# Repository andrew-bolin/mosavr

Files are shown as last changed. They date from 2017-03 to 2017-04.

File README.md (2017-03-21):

# mosavr
Modular Open-Source Audio (Visual?) Receiver

I'm building a modular open-source AV receiver platform, with the following features
- Receive digital audio from TV via HDMI ARC
- Share control signals via HDMI CEC
- Multi-channel audio decoding and amplification
- Multiple outputs
- Apply DSP effects

Use-cases:
- Allow your TV remote to seamlessly control an existing analog amplifier/receiver
- Send a mono mixdown from your home cinema to the bathroom
- Room/speaker compensation
- Start with a 2.0 system, later upgrade to 5.1 

See https://hackaday.io/project/20469-modular-open-source-av-receiver for more detail on progress.

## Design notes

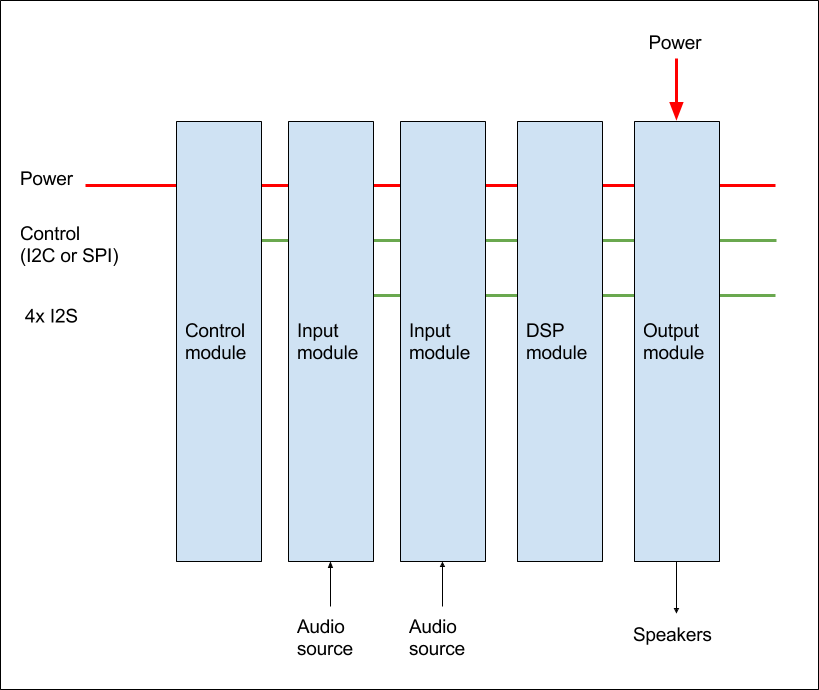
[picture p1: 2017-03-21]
docs/block dia.png

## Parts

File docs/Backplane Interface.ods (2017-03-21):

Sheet: Backplane Pinout
For counting purposes only... |  |  |  |  | Module dimensions (ideas)
A0 | 1 | 2 | A3? | Module (EEPROM) address | Low-profile PCI card: 64.41mm high, 119.91mm long, 15.24mm wide [between slots]
A1 | 3 | 4 | A4? |  | PCI-express x1 connectors have 18x2 pins, cost 50c ea
A2 | 5 | 6 | A5? |  | http://au.mouser.com/ProductDetail/Amphenol-FCI/10018784-10210TLF/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
Gnd | 7 | 8 |  |  | http://au.element14.com/amphenol-fci/10018783-10200tlf/card-edge-connector-receptacle/dp/1924223
3v3 | 9 | 10
 | 11 | 12
SCL | 13 | 14 | SDA
Gnd | 15 | 16 |  |  | 64-pin PCIe socket from 80c. I could kinda even use their pinout as inspiration...
MCLK | 17 | 18 |  | Depending on module’s capabilities and control instructions, these may be modified before being passed along | 98-pin ~$1.30
SCLK | 19 | 20 |  |  | 164-pin ~$1.05 (?!)
LRCLK | 21 | 22 |  |  | If I don't follow PCIe pinout, might make layout easier if Gnds on solder side and Vcc is on component side? [marginal]
I2S0 | 23 | 24 |  |  | (Probably want more grounds near the high-speed signals...)
I2S1 | 25 | 26
I2S2 | 27 | 28
I2S3 | 29 | 30 |  |  | TODO:
Gnd | 31 | 32 |  |  | Current rating per pin?
3v3 | 33 | 34 |  |  | Power budget for an average module
12v? | 35 | 36 |  | End of PCIe x1 | If I include a higher voltage, what is a sensible value? (Would +/- rails be of benefit, or just add rarely used complexity?)
 | 37 | 38
 | 39 | 40

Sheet: ID EEPROM
Chip | Memory | I/O | Addresses | Digikey Cost (AUD, qty 1) | Mouser (AUD) | element14 (AUD)
DS4250 | 64B | 9 | 8 | $4 | $4 | $6.75
PCA9500 | 256B | 8 | 8 | $2.50 | $2.60 | $2.60
PCA9501 | 256B | 8 | 64 | $2.70 | $2.70 | $2.70

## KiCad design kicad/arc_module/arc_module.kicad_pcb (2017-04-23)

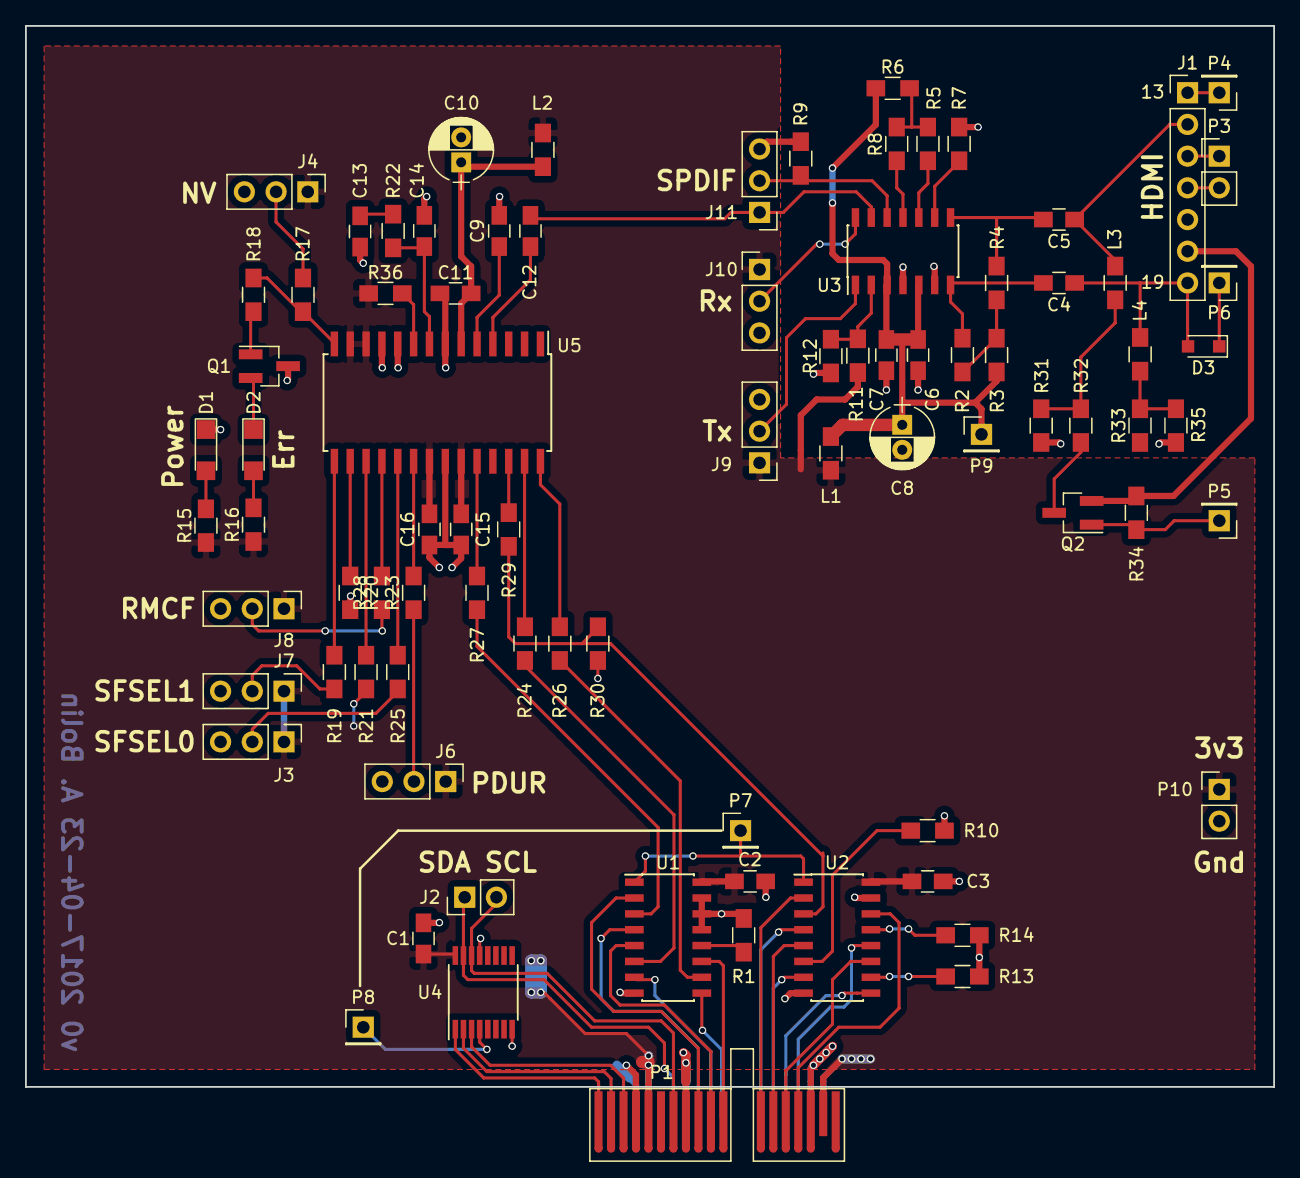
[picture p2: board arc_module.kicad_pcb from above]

Board: 2 copper layers, 100.0 x 85.0 mm, 85 parts (0 on the bottom side), 80 nets.

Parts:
C1, C2, C3: 0.1uF; C_0805_HandSoldering
C4, C5: 1u; C_0805_HandSoldering
C6, C7, C11, C15, C16: 0.1u; C_0805_HandSoldering
C8: 47u; CP_Radial_D5.0mm_P2.00mm
C9, C12: 0.01u; C_0805_HandSoldering
C10: 10u; CP_Radial_D5.0mm_P2.00mm
C13, C14: C_Small; C_0805_HandSoldering
D1, D2: LED_Small; LED_1206
D3: BAS16H; D_SOD-323_HandSoldering
J1: CONN_01X07; Pin_Header_Straight_1x07_Pitch2.54mm
J2: CONN_01X02; Pin_Header_Straight_1x02_Pitch2.54mm
J3, J4, J6, J7, J8, J9, J10, J11: CONN_01X03; Pin_Header_Straight_1x03_Pitch2.54mm
L1: 300ohm @ 100MHz; L_0805_HandSoldering
L2: Ferrite_Bead_Small; L_0805_HandSoldering
L3, L4: 300; L_0805_HandSoldering
P1: pcie_1x_edge; PCI-EXPRESS
P3, P10: CONN_01X02; Pin_Header_Straight_1x02_Pitch2.54mm
P4, P5, P6, P7, P8, P9: CONN_01X01; Pin_Header_Straight_1x01_Pitch2.54mm
Q1: BC847; SOT-23_Handsoldering
Q2: NTR4502; SOT-23_Handsoldering
R1, R9, R10, R13, R14, R34: 10k; R_0805_HandSoldering
R2, R4, R5, R8: 49.9; R_0805_HandSoldering
R3, R6: 5.1; R_0805_HandSoldering
R7: 39k; R_0805_HandSoldering
R11, R12: 1k; R_0805_HandSoldering
R15, R16, R22: R_Small; R_0805_HandSoldering
R17, R18, R19, R20, R21, R23, R25, R28, R30, R36: 47k; R_0805_HandSoldering
R24, R26, R27, R29: 33R; R_0805_HandSoldering
R31, R35: 5k1; R_0805_HandSoldering
R32, R33: 1k2; R_0805_HandSoldering
U1, U2: 74HCT157; SOIC-16_3.9x9.9mm_Pitch1.27mm
U3: EP91H0; SOIC-14_3.9x8.7mm_Pitch1.27mm
U4: PCA9500; TSSOP-16_4.4x5mm_Pitch0.65mm
U5: CS8416; SOIC-28W_7.5x17.9mm_Pitch1.27mm

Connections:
+3V3: C1.1, C2.1, C3.1, C15.1, C16.1, J3.1, J4.1, J6.1, J7.1, J8.1, J9.1, J10.1, L1.1, L2.2, P1.A5, P1.A17, P1.B5, P1.B17, P10.1, R11.1, R15.1, R16.1, R21.2, R36.2, U1.16, U2.16, U4.16, U5.12, U5.13, U5.21, U5.23
+5V: J1.6, Q2.2, R34.2
/CEC: J1.1, P4.1
/CS8416/LR_clk: R26.1, U1.10
/CS8416/M_clk: R27.1, U1.3
/CS8416/PDUR: J6.2, R23.1
/CS8416/RM/NV: J4.2, R17.2
/CS8416/RMCF: J8.2, R28.1
/CS8416/SFSEL0: J3.2, R25.1
/CS8416/SFSEL1: J7.2, R19.2
/CS8416/S_clk: R24.1, U1.6
/HDMI_HotPlug: D3.1, P6.1
/HDMI_SCL: J1.3, P3.1
/HDMI_SDA: J1.4, P3.2
/HEAC+: C5.1, J1.2, L3.2
/HEAC-: C4.1, D3.2, J1.7, L4.2
/Module Common/A0: P1.B1, U4.1
/Module Common/A1: P1.B2, U4.2
/Module Common/A2: P1.B3, U4.3
/Module Common/I2S0_in: P1.B12, U2.2
/Module Common/I2S0_mod: R29.1, R30.2, U2.3
/Module Common/I2S0_out: P1.A12, U2.4
/Module Common/I2S1_in: P1.B13, U2.5
/Module Common/I2S1_mod: R10.2, U2.6
/Module Common/I2S1_out: P1.A13, U2.7
/Module Common/I2S2_in: P1.B14, U2.11
/Module Common/I2S2_mod: R13.2, U2.10
/Module Common/I2S2_out: P1.A14, U2.9
/Module Common/I2S3_in: P1.B15, U2.14
/Module Common/I2S3_mod: R14.2, U2.13
/Module Common/I2S3_out: P1.A15, U2.12
/Module Common/IO0: P7.1, P8.1, U1.1, U2.1, U4.4
/Module Common/LRclk_in: P1.B11, U1.11
/Module Common/LRclk_out: P1.A11, U1.9
/Module Common/Mclk_in: P1.B9, U1.2
/Module Common/Mclk_out: P1.A9, U1.4
/Module Common/SCL: J2.2, P1.B7, U4.14
/Module Common/SDA: J2.1, P1.A7, U4.15
/Module Common/Sclk_in: P1.B10, U1.5
/Module Common/Sclk_out: P1.A10, U1.7
/Rx_En: J10.2, U3.14
/SPD_Rx: C12.2, J11.1, U3.13
/SPD_Tx: J11.2, R9.1, U3.12
/Tx_En: J9.2, U3.1
/arc tx/Ctrl_Tx: P5.1, Q2.1, R34.1
GND: C1.2, C2.2, C3.2, C6.2, C7.2, C8.2, C9.2, C10.2, C11.2, C13.2, C14.2, C15.2, C16.2, D1.1, J1.5, J3.3, J4.3, J6.3, J7.3, J8.3, J9.3, J10.3, J11.3, P1.A4, P1.A8, P1.A16, P1.B4, P1.B8, P1.B16, P10.2, Q1.3, R1.1, R7.2, R9.2, R10.1, R12.2, R13.1, R14.1, R20.2, R30.1, R31.2, R35.1, U1.8, U1.13, U1.14, U1.15, U2.8, U2.15, U3.4, U3.6, U4.8, U4.13, U5.7, U5.10, U5.11, U5.22, U5.25
unnamed: C4.2, R2.2, U3.7
unnamed: C5.2, R4.2, U3.8
unnamed: C9.1, U5.5
unnamed: C10.1, C11.1, L2.1, U5.6
unnamed: C12.1, U5.4
unnamed: C13.1, R22.2
unnamed: C14.1, R22.1, U5.8
unnamed: D1.2, R15.2
unnamed: D2.1, Q1.2
unnamed: D2.2, R16.2
unnamed: L3.1, R31.1, R32.2
unnamed: L4.1, R33.2, R35.2
unnamed: Q1.1, R18.2
unnamed: Q2.3, R32.1, R33.1
unnamed: R1.2, U1.12
unnamed: R2.1, R3.2, R4.1
unnamed: R5.1, R6.2, R8.1
unnamed: R5.2, U3.10
unnamed: R7.1, U3.9
unnamed: R8.2, U3.11
unnamed: R11.2, R12.1, U3.2
unnamed: R17.1, R18.1, U5.14
unnamed: R19.1, U5.15
unnamed: R20.1, U5.16
unnamed: R21.1, U5.17
unnamed: R23.2, U5.20
unnamed: R24.2, U5.27
unnamed: R25.2, U5.19
unnamed: R26.2, U5.28
unnamed: R27.2, U5.24
unnamed: R28.2, U5.18
unnamed: R29.2, U5.26
unnamed: R36.1, U5.9
VDDA: C6.1, C7.1, C8.1, L1.2, P9.1, R3.1, R6.1, U3.3, U3.5

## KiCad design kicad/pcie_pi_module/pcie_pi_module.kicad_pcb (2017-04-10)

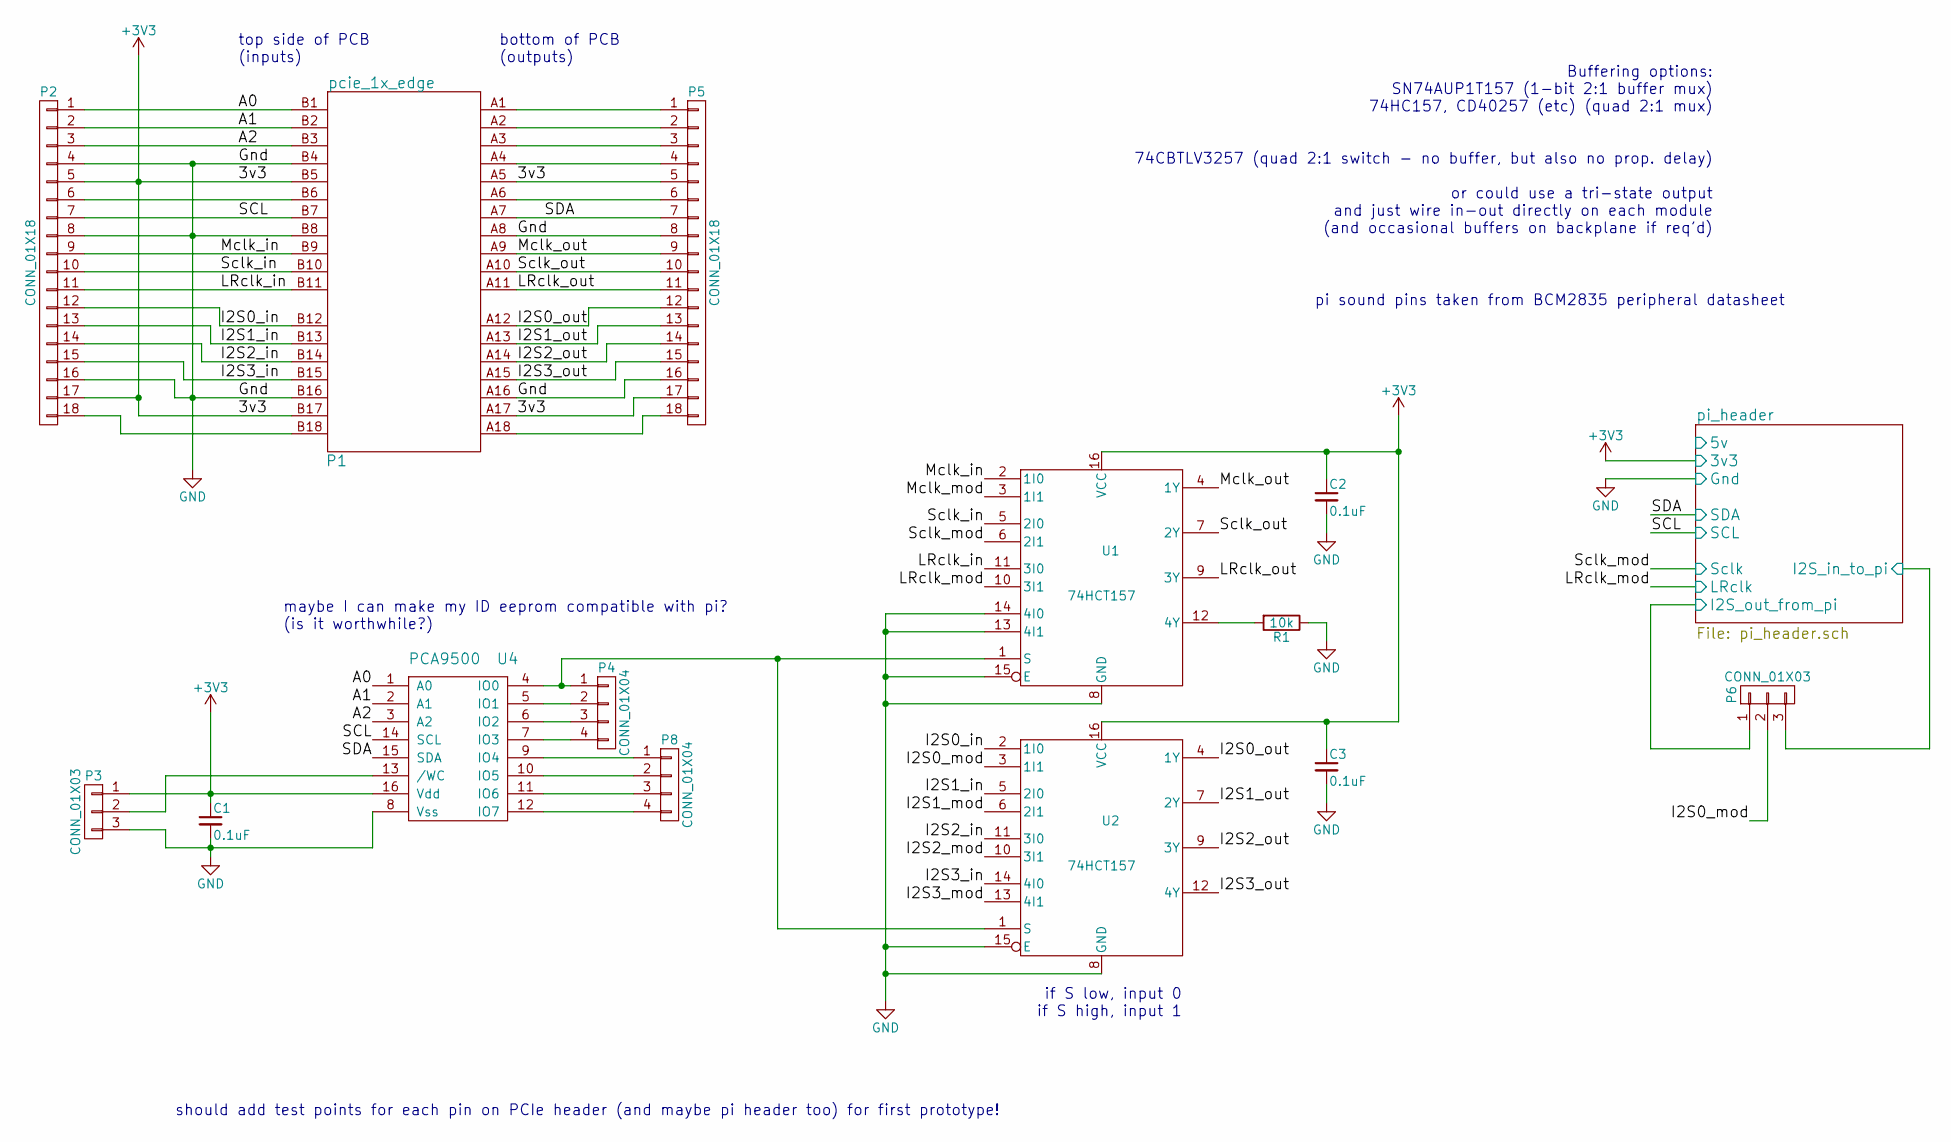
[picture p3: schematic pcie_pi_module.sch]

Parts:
C1, C2, C3: 0.1uF; C_0805_HandSoldering
P1: pcie_1x_edge; PCI-EXPRESS
P2, P5: CONN_01X18; smd_1x18_B
P3, P6: CONN_01X03; Pin_Header_Straight_1x03
P4, P8: CONN_01X04; Pin_Header_Straight_1x04
R1: 10k; R_0805_HandSoldering
U1, U2: 74HCT157; SOIC-16_3.9x9.9mm_Pitch1.27mm
U4: PCA9500; TSSOP-16_4.4x5mm_Pitch0.65mm

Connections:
+3V3: C1.1, C2.1, C3.1, P1.A5, P1.A17, P1.B5, P1.B17, P2.5, P2.17, P3.1, P5.5, P5.17, U1.16 (VCC), U2.16 (VCC), U4.16 (Vdd); also elsewhere on the board
/A0: P1.B1, P2.1, U4.1 (A0)
/A1: P1.B2, P2.2, U4.2 (A1)
/A2: P1.B3, P2.3, U4.3 (A2)
/I2S0_in: P1.B12, P2.12, U2.2 (1I0)
/I2S0_mod: P6.2, U2.3 (1I1)
/I2S0_out: P1.A12, P5.12, U2.4 (1Y)
/I2S1_in: P1.B13, P2.13, U2.5 (2I0)
/I2S1_mod: U2.6 (2I1)
/I2S1_out: P1.A13, P5.13, U2.7 (2Y)
/I2S2_in: P1.B14, P2.14, U2.11 (3I0)
/I2S2_mod: U2.10 (3I1)
/I2S2_out: P1.A14, P5.14, U2.9 (3Y)
/I2S3_in: P1.B15, P2.15, U2.14 (4I0)
/I2S3_mod: U2.13 (4I1)
/I2S3_out: P1.A15, P5.15, U2.12 (4Y)
/LRclk_in: P1.B11, P2.11, U1.11 (3I0)
/LRclk_mod: U1.10 (3I1); also elsewhere on the board
/LRclk_out: P1.A11, P5.11, U1.9 (3Y)
/Mclk_in: P1.B9, P2.9, U1.2 (1I0)
/Mclk_mod: U1.3 (1I1)
/Mclk_out: P1.A9, P5.9, U1.4 (1Y)
/SCL: P1.B7, P2.7, U4.14 (SCL); also elsewhere on the board
/SDA: P1.A7, P5.7, U4.15 (SDA); also elsewhere on the board
/Sclk_in: P1.B10, P2.10, U1.5 (2I0)
/Sclk_mod: U1.6 (2I1); also elsewhere on the board
/Sclk_out: P1.A10, P5.10, U1.7 (2Y)
/pi_header/I2S_in_to_pi: P6.3; also elsewhere on the board
/pi_header/I2S_out_from_pi: P6.1; also elsewhere on the board
GND: C1.2, C2.2, C3.2, P1.A8, P1.A16, P1.B4, P1.B8, P1.B16, P2.4, P2.8, P2.16, P3.3, P5.8, P5.16, R1.1, U1.8 (GND), U1.13 (4I1), U1.14 (4I0), U1.15 (E), U2.8 (GND), U2.15 (E), U4.8 (Vss); also elsewhere on the board
unnamed: P1.A1, P5.1
unnamed: P1.A2, P5.2
unnamed: P1.A3, P5.3
unnamed: P1.A4, P5.4
unnamed: P1.A6, P5.6
unnamed: P1.A18, P5.18
unnamed: P1.B6, P2.6
unnamed: P1.B18, P2.18
unnamed: P3.2, U4.13 (/WC)
unnamed: P4.1, U1.1 (S), U2.1 (S), U4.4 (IO0)
unnamed: P4.2, U4.5 (IO1)
unnamed: P4.3, U4.6 (IO2)
unnamed: P4.4, U4.7 (IO3)
unnamed: P8.1, U4.9 (IO4)
unnamed: P8.2, U4.10 (IO5)
unnamed: P8.3, U4.11 (IO6)
unnamed: P8.4, U4.12 (IO7)
unnamed: R1.2, U1.12 (4Y)

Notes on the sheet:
top side of PCB (inputs)
bottom of PCB (outputs)
if S low, input 0 if S high, input 1
Buffering options: SN74AUP1T157 (1-bit 2:1 buffer mux) 74HC157, CD40257 (etc) (quad 2:1 mux) 74CBTLV3257 (quad 2:1 switch - no buffer, but also no prop. delay) or could use a tri-state output and just wire in-out directly on each module (and occasional buffers on backplane if req'd)
maybe I can make my ID eeprom compatible with pi? (is it worthwhile?)
pi sound pins taken from BCM2835 peripheral datasheet
should add test points for each pin on PCIe header (and maybe pi header too) for first prototype!

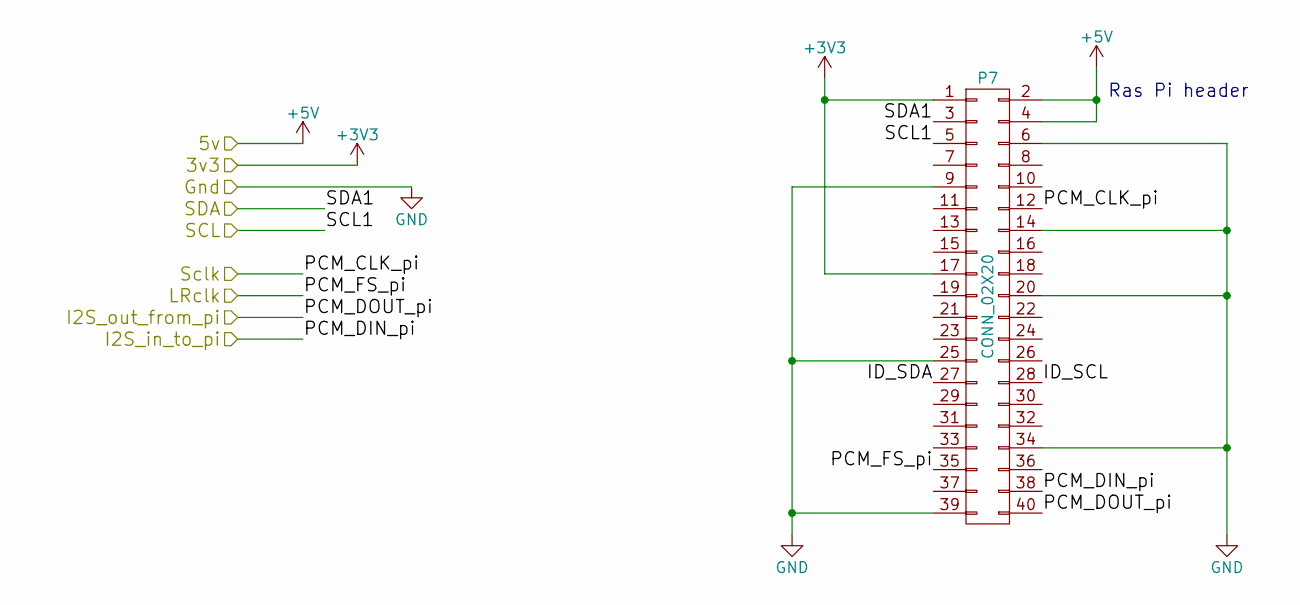
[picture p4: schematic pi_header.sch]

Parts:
P7: CONN_02X20; Pin_Header_Straight_2x20

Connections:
+3V3: P7.1, P7.17; also elsewhere on the board
+5V: P7.2, P7.4
/LRclk_mod: P7.35; also elsewhere on the board
/SCL: P7.5; also elsewhere on the board
/SDA: P7.3; also elsewhere on the board
/Sclk_mod: P7.12; also elsewhere on the board
/pi_header/I2S_in_to_pi: P7.38; also elsewhere on the board
/pi_header/I2S_out_from_pi: P7.40; also elsewhere on the board
/pi_header/ID_SCL: P7.28
/pi_header/ID_SDA: P7.27
GND: P7.6, P7.9, P7.14, P7.20, P7.25, P7.34, P7.39; also elsewhere on the board

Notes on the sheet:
Ras Pi header

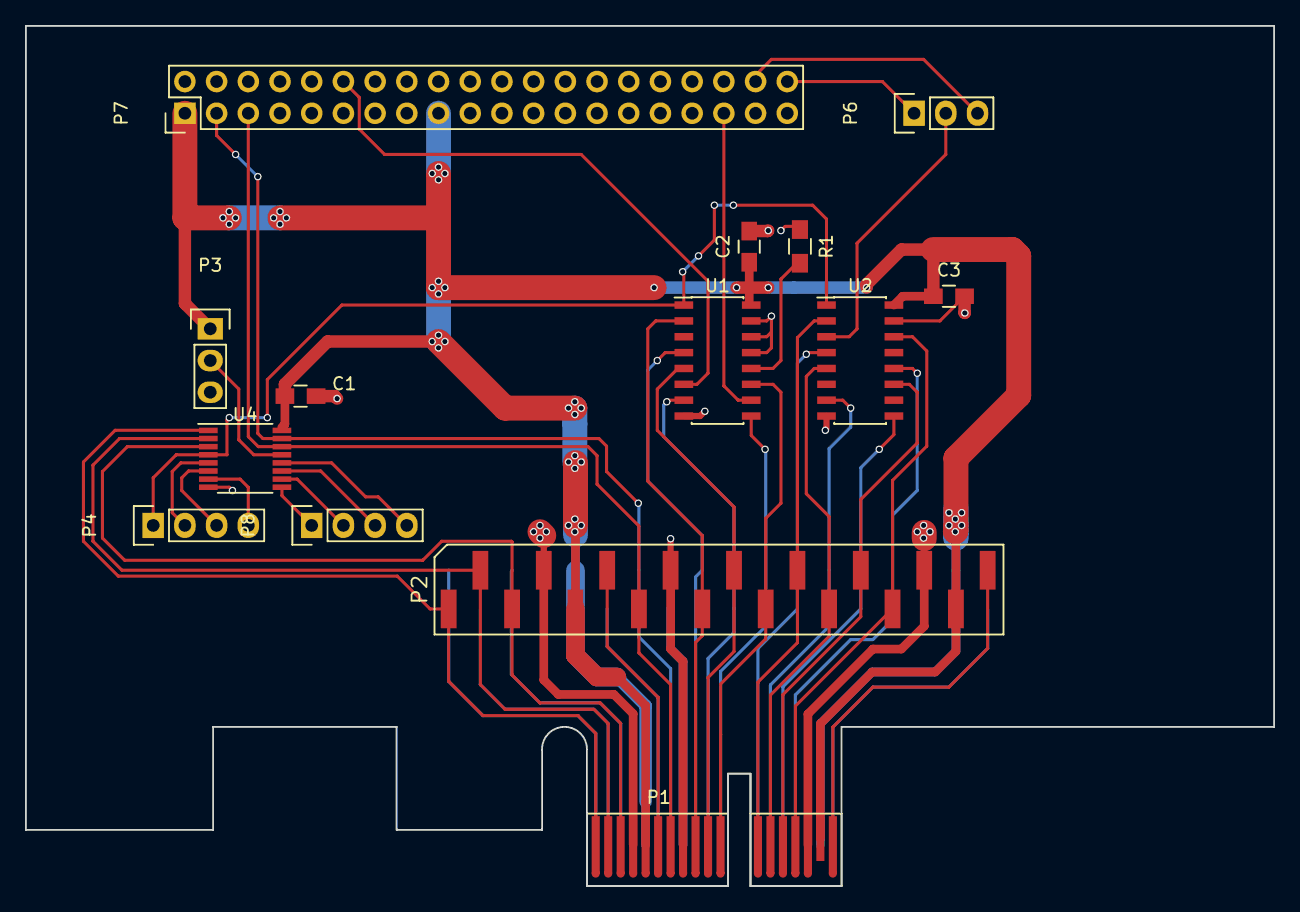
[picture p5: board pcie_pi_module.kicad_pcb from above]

Board: 2 copper layers, 100.0 x 68.9 mm, 15 parts (1 on the bottom side), 45 nets.

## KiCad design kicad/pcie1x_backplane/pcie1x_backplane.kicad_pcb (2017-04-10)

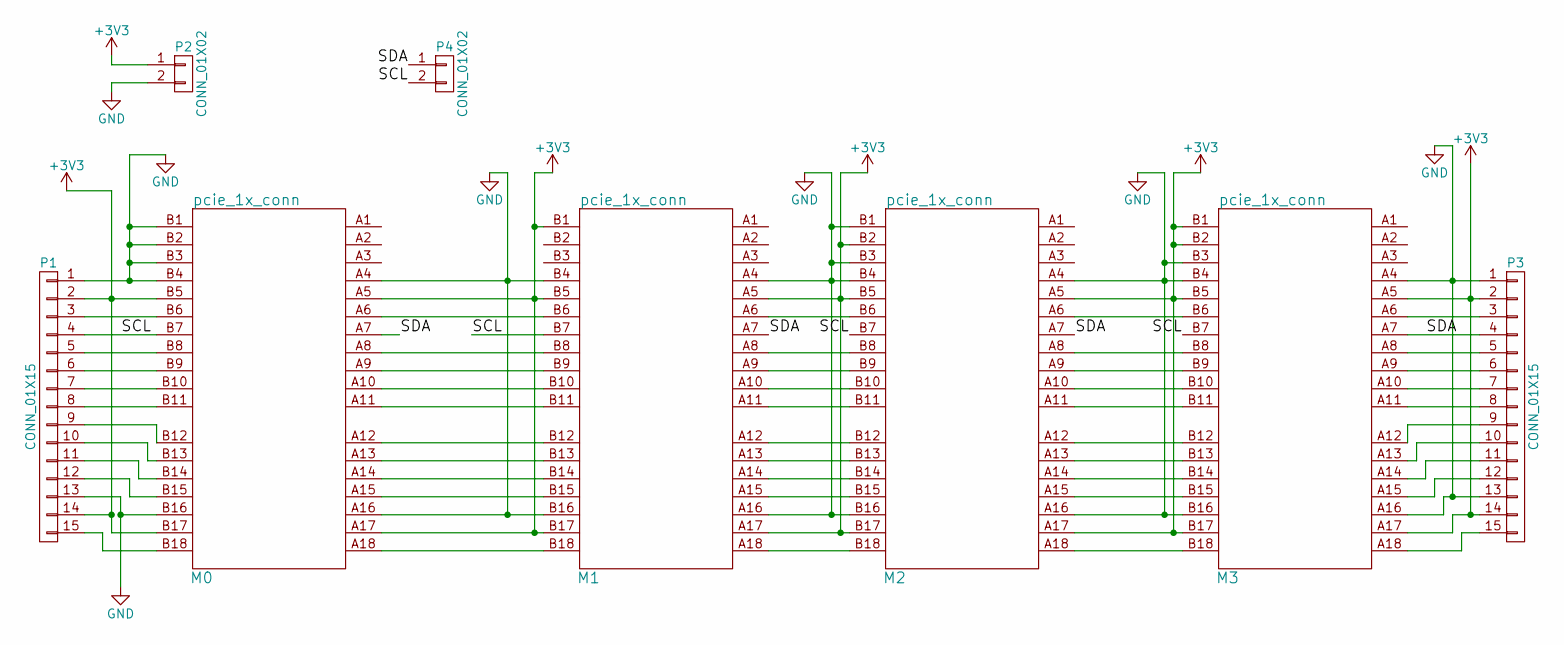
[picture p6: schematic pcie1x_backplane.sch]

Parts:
M0, M1, M2, M3: pcie_1x_conn; x1socket
P1, P3: CONN_01X15; Pin_Header_Straight_1x15
P2, P4: CONN_01X02; Pin_Header_Straight_1x02

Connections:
+3V3: M0.A5, M0.A17, M0.B5, M0.B17, M1.A5, M1.A17, M1.B1, M1.B5, M1.B17, M2.A5, M2.A17, M2.B2, M2.B5, M2.B17, M3.A5, M3.A17, M3.B1, M3.B2, M3.B5, M3.B17, P1.2, P1.14, P2.1, P3.2, P3.14
/SCL: M0.B7, M1.B7, M2.B7, M3.B7, P1.4, P4.2
/SDA: M0.A7, M1.A7, M2.A7, M3.A7, P3.4, P4.1
GND: M0.A4, M0.A16, M0.B1, M0.B2, M0.B3, M0.B4, M0.B16, M1.A4, M1.A16, M1.B4, M1.B16, M2.A4, M2.A16, M2.B1, M2.B3, M2.B4, M2.B16, M3.A4, M3.A16, M3.B3, M3.B4, M3.B16, P1.1, P1.13, P2.2, P3.1, P3.13
unnamed: M0.A6, M1.B6
unnamed: M0.A8, M1.B8
unnamed: M0.A9, M1.B9
unnamed: M0.A10, M1.B10
unnamed: M0.A11, M1.B11
unnamed: M0.A12, M1.B12
unnamed: M0.A13, M1.B13
unnamed: M0.A14, M1.B14
unnamed: M0.A15, M1.B15
unnamed: M0.A18, M1.B18
unnamed: M0.B6, P1.3
unnamed: M0.B8, P1.5
unnamed: M0.B9, P1.6
unnamed: M0.B10, P1.7
unnamed: M0.B11, P1.8
unnamed: M0.B12, P1.9
unnamed: M0.B13, P1.10
unnamed: M0.B14, P1.11
unnamed: M0.B15, P1.12
unnamed: M0.B18, P1.15
unnamed: M1.A6, M2.B6
unnamed: M1.A8, M2.B8
unnamed: M1.A9, M2.B9
unnamed: M1.A10, M2.B10
unnamed: M1.A11, M2.B11
unnamed: M1.A12, M2.B12
unnamed: M1.A13, M2.B13
unnamed: M1.A14, M2.B14
unnamed: M1.A15, M2.B15
unnamed: M1.A18, M2.B18
unnamed: M2.A6, M3.B6
unnamed: M2.A8, M3.B8
unnamed: M2.A9, M3.B9
unnamed: M2.A10, M3.B10
unnamed: M2.A11, M3.B11
unnamed: M2.A12, M3.B12
unnamed: M2.A13, M3.B13
unnamed: M2.A14, M3.B14
unnamed: M2.A15, M3.B15
unnamed: M2.A18, M3.B18
unnamed: M3.A6, P3.3
unnamed: M3.A8, P3.5
unnamed: M3.A9, P3.6
unnamed: M3.A10, P3.7
unnamed: M3.A11, P3.8
unnamed: M3.A12, P3.9
unnamed: M3.A13, P3.10
unnamed: M3.A14, P3.11
unnamed: M3.A15, P3.12
unnamed: M3.A18, P3.15

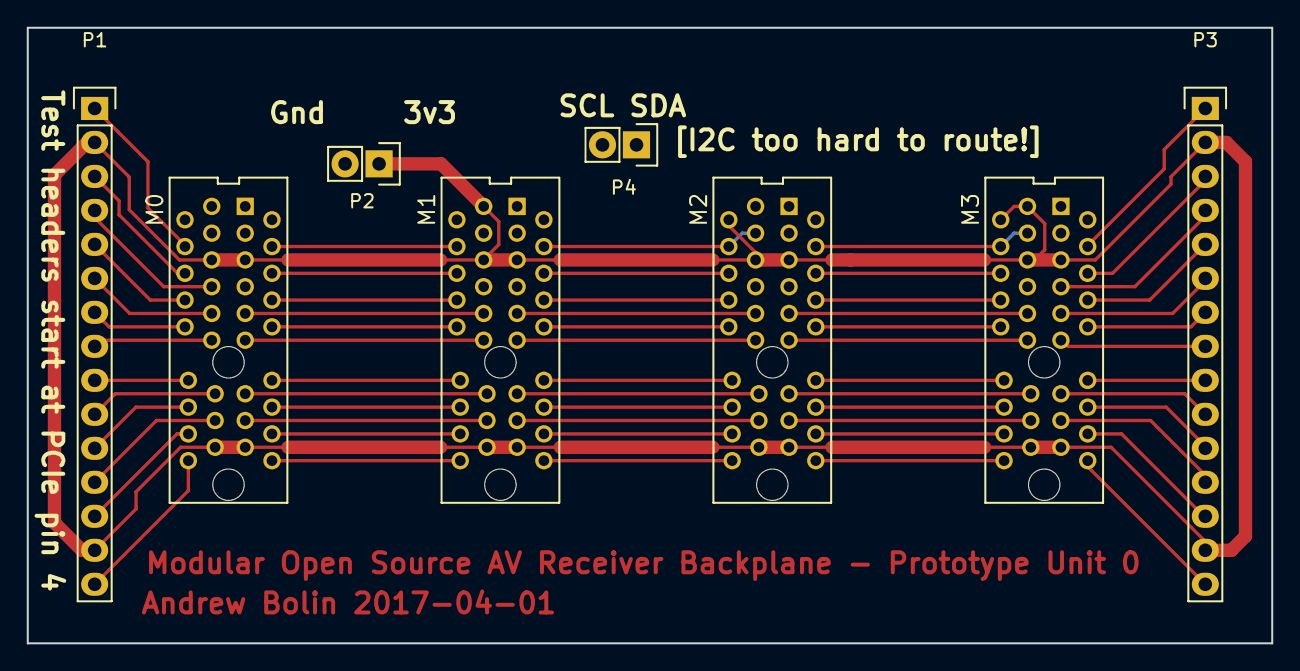
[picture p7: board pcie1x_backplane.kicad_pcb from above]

Board: 2 copper layers, 93.0 x 46.0 mm, 8 parts (0 on the bottom side), 54 nets.

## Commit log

2017-03-26 add mux & eeprom
    [pcie_conn_module.kicad_pcb, pcie_conn_module.sch]
2017-03-27 first draft schematic
    [pcie_conn_module.kicad_pcb, pcie_conn_module.sch, pi_header.sch]
2017-04-10 v0 PCBs for manufacture
    [pcie1x_backplane.kicad_pcb, pcie1x_backplane.sch, pcie_conn_module.kicad_pcb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]
2017-04-22 restructure & add ARC
    [CS8416.sch, arc_module.kicad_pcb, arc_module.sch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]
2017-04-23 draft layout
    [CS8416.sch, arc_module.kicad_pcb, arc_module.sch]
2017-04-23 removed 3v3A
    [CS8416.sch, module_common.sch]
2017-04-23 silkscreen & test points
    [arc_module.kicad_pcb, arc_module.sch, arc_module_tx.sch]
